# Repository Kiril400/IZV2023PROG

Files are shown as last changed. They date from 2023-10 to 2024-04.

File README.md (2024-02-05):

# Smart MeteoBox
Projekta galvenā ideja un mērķis ir izveidot digitālu ierīci, kas nodrošinās iespēju sēkot līdzi laikapstākļiem vidē, kur ierīce atrodas, mērot gaisa temperatūru, relatīvo gaisa mitrumu, kā arī atmosfēras spiedienu. Ierīce nodrošinās arī iespēju paredzēt laikapstākļus, balstoties uz augstāk minētiem lielumiem un šo lielumu izmaiņām laikā. Nepieciešamo informāciju ir paredzēts izvadīt uz ierīces ekrāna.
Projekta nosaukums ir Smart MeteoBox.

Izmantotās tehnoloģijas: C++, Arduino IDE. 

Dalībnieki: Kirils Koļesņikovs (darba plānā atzīmēts ar zaļo krāsu), Ilya Reutin (ar zilo), Varvara Gromova (ar oranžo)

Darba plāns 02/10 - 30/10:



Darba plāns 30/10 - 01/12:

Darba plāns 04/12 - 29/12:

Darba plāns 08/01 - 28/01

Darba plāns 05/02 - 02/03

Ierīces elektroshēma
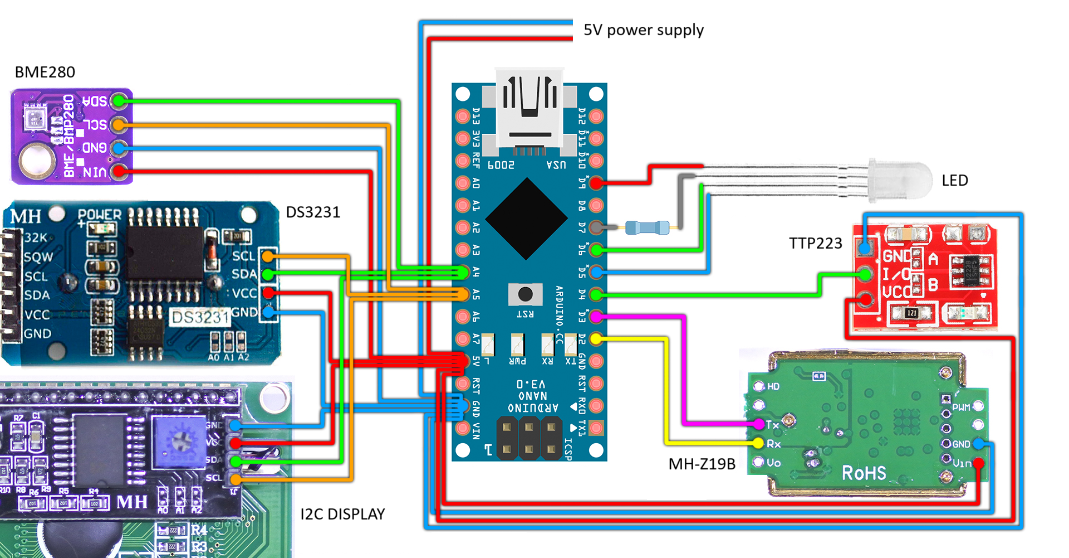
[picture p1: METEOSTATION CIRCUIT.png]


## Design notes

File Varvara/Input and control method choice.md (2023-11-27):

Sensoru pogām, kas pazīstamas arī kā kapacitatīvās skārienjutīgās vai skārienjutīgās pogas, ir priekšrocības salīdzinājumā ar tradicionālajām spiedpogu un potenciometriem, viens no galvenajiem ir izturība: sensoru pogām nav fizisku kustīgu detaļu, tādējādi samazinot to nolietojumu laika gaitā. Mehāniskās pogas var nolietoties atkārtotas lietošanas rezultātā, un potenciometri var nolietoties mehāniskā kontakta (berzes) dēļ.

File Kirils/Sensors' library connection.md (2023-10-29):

**Wire.h** - working. <BR> 
**GyverTime.h** - working, but some features are to be explored. <BR>
**GyverButton.h** - to do if we face trouble with button accident trigering. <BR>
**LiquidCrystal_I2C.h** - working. <BR>
**RTClib-master.h** - to do when sensor arrives. <BR>
**MHZ19_uart.h** - to do when sensor arrives. <BR>

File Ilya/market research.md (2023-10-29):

<h1>Portatīvo meteoroloģisko staciju un to funkcionalitātes tirgus izpēte</h1>
Portatīva meteostacijas ir kompaktas un multifunkcionālas ierīces, kas paredzētas, lai sniegtu aktuālo meteoroloģisko informāciju visdažādākajiem lietojumiem. Šajā tirgus pētījumā tiek izpētīti desmit dažādi portatīvo meteoroloģisko staciju modeļi, kā arī to galvenās funkcijas un īpašības, lai izspriestu, kādas funkcijas var padarīt jauno projektu par unikālu tirgū.<br>
<br>
<strong>1. Kestrel 5500 Weather Meter with LiNK:</strong><br>
Mājaslapa: https://kestrelmeters.com/products/kestrel-5500-weather-meter<br>
Funkcijas: mēra temperatūru, mitrumu, barometrisko spiedienu, vēja ātrumu, vēja virzienu, augstumu virs jūras līmeņa un aprēķina dažādus ar laikapstākļiem saistītus parametrus, piemēram, siltuma stresa indeksu un rasas punktu.<br>
<br>
<strong>2. Davis Instruments Vantage Vue Handheld Weather Station:</strong><br>
Mājaslapa: https://www.davisinstruments.com/products/vantage-vue-weather-station-with-weatherlink-console <br>
Funkcijas: Sniedz datus par temperatūru, mitrumu, barometrisko spiedienu, vēja ātrumu, vēja virzienu un nokrišņu daudzumu.<br>
<br>
<strong>3. AcuRite 01080M Pro Accuracy Portable Weather Station:</strong><br>
Mājaslapa: https://www.amazon.com/AcuRite-01080M-Accuracy-Temperature-Humidity/dp/B000XTJRRA <br>
Funkcijas: monitorē temperatūru, mitrumu, barometrisko spiedienu un vēja ātrumu. <br>
<br>
<strong>4. Ambient Weather WM-4 Handheld Weather Station:</strong><br>
Mājaslapa: https://ambientweather.com/amwm4-html <br>
Funkcijas: mēra temperatūru, vēja ātrumu, vēja virzienu un vēja vēsumu.<br>
<br>
<strong>5. Brunton ADC Pro Handheld Weather Station:</strong><br>
Mājaslapa: https://www.amazon.com/Brunton-Atmospherice-Data-Center-Wind/dp/B000FKMUDU?th=1 <br>
Funkcijas: sniedz datus par temperatūru, mitrumu, barometrisko spiedienu, augstumu un dažādām laikapstākļu prognozēm.<br>
<br>
<strong>6. La Crosse Technology C83332 Handheld Weather Station:</strong><br>
Mājaslapa: https://www.lacrossetechnology.com/products/c83332 <br>
Funkcijas: nosaka temperatūru, mitrumu, barometrisko spiedienu un augstumu virs jūras līmeņa.<br>
<br>
<strong>7. Proster Digital Anemometer Handheld Weather Station:</strong><br>
Mājaslapa: https://www.amazon.com/Proster-Anemometer-Thermometer-Backlight-Collection/dp/B01FTPX566 <br>
Funkcijas: Mēra vēja ātrumu, vēja vēsumu, temperatūru un mitrumu.<br>
<br>
<strong>8. Oregon Scientific BAR208HGX Handheld Weather Station:</strong><br>
Mājaslapa: https://www.oregonscientificstore.com/p-458-oregon-scientific-bar208hgx-advanced-wireless-weather-station-with-humidity-radio-controlled-clock-and-weather-forecast.a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 <br>
Funkcijas: sniedz datus par temperatūru, mitrumu, barometrisko spiedienu un laika prognozes.<br>
<br>
<strong>9. Casio Pro Trek PRG270-1 Handheld Weather Station Watch:</strong> <br>
Mājaslapa: https://www.casio.com/products/watches/pro-trek/prg270-1 <br>
Funkcijas: apvieno rokas pulksteni ar laikapstākļu funkcijām, tostarp temperatūru, barometrisko spiedienu, augstumu virs jūras līmeņa un kompasu.<br>
<br>
<strong>10. Skywatch Xplorer 1 Handheld Weather Station:</strong><br>
Mājaslapa: https://www.darrera.com/wp/en/product/12401-skywatch-xplorer-1/ <br>
Funkcijas: Mēra vēja ātrumu, temperatūru un vēja vēsumu. Tas ir kompakts un izturīgs.<br>
<br>
Lai gan šīs rokas meteoroloģiskās stacijas piedāvā virkni funkciju laikapstākļu izpētei, tām nav iespējas izvadīt laikapstākļu statistiku noteiktam laika periodam. Šī funkcija ir unikāls mūsu projekta aspekts, kas atšķir mūsu produktu no pārējiem tirgū esošajiem modeļiem.<br>

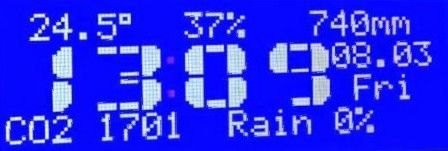
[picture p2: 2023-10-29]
Kirils/main screen design.jpg

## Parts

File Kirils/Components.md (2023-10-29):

**Arduino NANO:**<BR>
Kompakta plate, kas balstīta uz ATmega328P. Tā piedāvā tādu pašu funkcionalitāti kā Arduino Uno, bet mazākā iepakojumā.  

**Sensora poga (TTP223):**<BR> Ierīce, kas uztver fizisku ievadi pat caur planu plastiku un nosūta signālu mikrokontrolierim. Tā ir vienkārši lietojama un viegli intergrējama.

**BME280 (5V):**<BR> Precīzs Bosch sensors, kas mēra mitrumu, spiedienu un temperatūru. Liela precizitāte un zems enerģijas patēriņš.

**MH-Z19**:<BR> Infrasarkanais CO2 sensors iekštelpu gaisa kvalitātes monitorēšanai. To slavē par augstu jutību un ilgtermiņa stabilitāti.

**Display2004 i2c:**<BR> 20x4 rakstzīmju LCD modulis ar I2C interfeisu. To novērtē par tā lietošanas ērtumu un skaidru displeju.

**DS3231:** <BR>Ļoti precīzs reālā laika pulksteņa modulis. Tam ir integrēts temperatūras kompensēts kristāla oscilators, nodrošinot lielisku laika norādi.<br><br>
**Visas komponentes ir iegadajāmas Lemona.lv vai aliexpress.com**

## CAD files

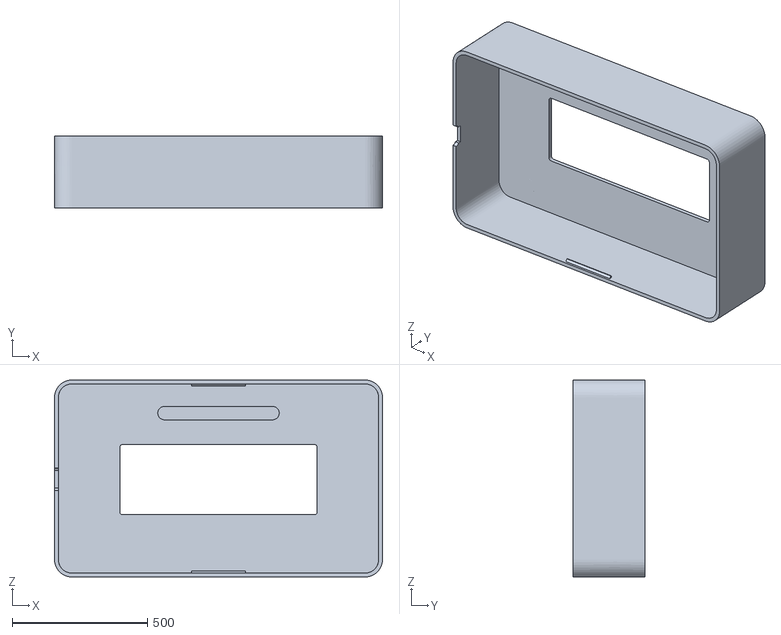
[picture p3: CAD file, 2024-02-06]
3D model/MeshBody1.stl
1213.8 x 265.0 x 728.8

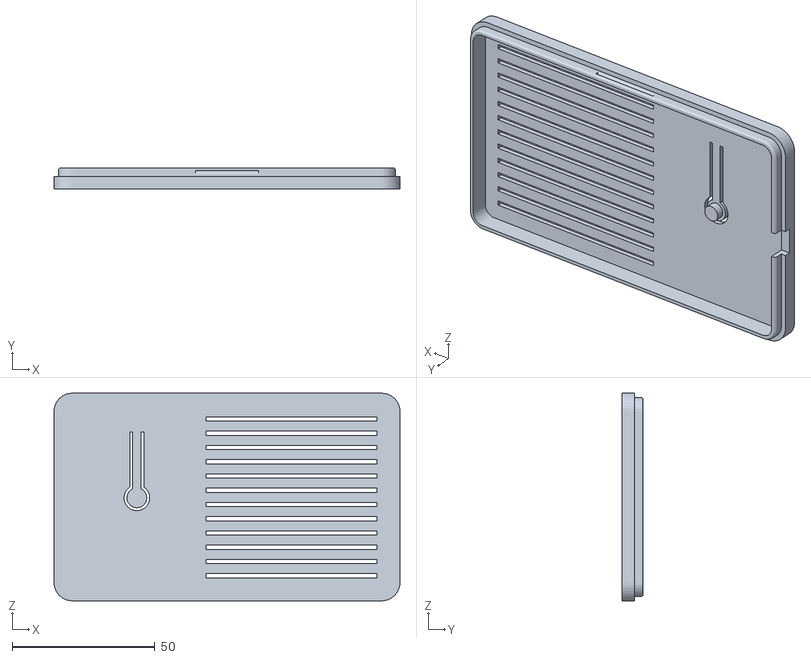
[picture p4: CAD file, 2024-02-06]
3D model/Meteo Clock Enclosure v16 - Back.stl
121.4 x 7.50 x 72.9

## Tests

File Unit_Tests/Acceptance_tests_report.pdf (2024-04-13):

## Smart MeteoBox: akcepttesti

Funkcijas, Darbības apraksts, nozīme | Ievade/Darbība | Sagaidāmais rezultāts | Rezultāts
Funkcija ciparu izvadīšanai uz ekrāna | DrawDIG(0) | Tiek izvadīts cipars 0 | Tiek izvadīts cipars 0
| drawDIG(1) | Tiek izvadīts cipars 1 | Tiek izvadīts cipars 1
| drawDIG(a) | Tiek izvadīta kļūda | Nekas netiek izvadīts
| drawDIG(+) | Tiek izvadīta kļūda | Nekas netiek izvadīts
Funkcija punktu un atstarpju izvadīšanai | drawdot(3,2,1) | Punkts ar koord. (3,1) | Punkts ar koord. (3,1)
| drawdot(8,1,1) | Punkts ar koord. (8,1) | Punkts ar koord. (8,1)
| drawdot(8,1,0) | Punkts netiek izvadīts | Punkts netiek izvadīts
| drawdot(40,1,1) | Tiek izvadīta kļūda | Nekas netiek izvadīts
| drawdot(a,1,1) | Tiek izvadīta kļūda | Nekas netiek izvadīts
Funkcija laika izvadīšanai uz ekrānā formātā hh,mm | drawClock(14,36) | Tiek izvadīts laiks 14,36 | Tiek izvadīts laiks 14,36
| drawClock(23,59) | Tiek izvadīts laiks 23,59 | Tiek izvadīts laiks 23,59
| drawClock(0,00) | Tiek izvadīts laiks 0,00 | Tiek izvadīts laiks 0,00
| drawClock(1,89) | Tiek izvadīta kļūda | Tiek izvadīts laika 1,89
| drawClock(a,19) | Tiek izvadīta kļūda | Nekas netiek izvadīts
Funkcija datuma izvadīšanai uz ekrānā formātā dd,mm | drawData(15,07) | Tiek izvadīts datums 15,07 | Tiek izvadīts datums 15,07
| drawData(2,3) | Tiek izvadīts datums 2,3 | Tiek izvadīts datums 2,3
| drawData(1,1) | Tiek izvadīts datums 1,1 | Tiek izvadīts datums 1,1
| drawData(31,12) | Tiek izvadīts datums 31,12 | Tiek izvadīts datums 31,12
| drawData(30,2) | Tiek izvadīta kļūda | Tiek izvadīts datums 30,2
| drawData(a,2) | Tiek izvadīta kļūda | Nekas netiek izvadīts
Funkcija LED gaismas krāsu definēšanai | setLED(0) | Nespīd | Nespīd
| setLED(1) | Spīd sarkana gaisma | Spīd sarkanā gaisma
| setLED(2) | Spīd zaļā gaisma | Spīd zaļā gaisma
| setLED(3) | Spīd zilā gaisma | Spīd zilā gaisma
| setLED(4) | Nekas nenotiek | Nekas nenotiek
| setLED(a) | Nekas nenotiek | Nekas nenotiek
Funkcija ekrāna spilgtuma mainīšanai atkarībā no apkārtējas vides | checkBrightness(analogRead(LIGHT_SENS) < BRIGHT_LIMIT) | Ekrāns kļūst tumšāks | Ekrāns kļūst tumšāks
| checkBrightness(analogRead(LIGHT_SENS) > BRIGHT_LIMIT) | Ekrāns kļūst gaišāks | Ekrāns kļūst gaišāks

Funkcija ekrānu pārslēgšanai ar pogu | modesTick(button.isClick()) | Ekrāns pārslēdzas uz nākamo | Ekrāns nepārslēdzas uz nākamo
| modesTick(button.isHolded()) | Ekrāns pārslēdzas uz galveno | Ekrāns nepārslēdzas uz galveno
| redrawPlot(1) | Zīmē temperatūras grafiku pēdejās stundas laikā | Zīmē temperatūras grafiku pēdejās stundas laikā
| redrawPlot(2) | Zīmē temperatūras grafiku pēdējo 24 stundu laikā | Zīmē temperatūras grafiku pēdējo 24 stundu laikā
| redrawPlot(3) | Zīmē relatīvā mitruma grafiku pēdejās stundas laikā | Zīmē relatīvā mitruma grafiku pēdejās stundas laikā
| redrawPlot(4) | Zīmē relatīvā mitruma grafiku pēdējo 24 stundu laikā | Zīmē relatīvā mitruma grafiku pēdējo 24 stundu laikā
| redrawPlot(5) | Zīmē spiediena grafiku pēdejās stundas laikā | Zīmē spiediena grafiku pēdejās stundas laikā
| redrawPlot(6) | Zīmē spiediena grafiku pēdējo 24 stundu laikā | Zīmē spiediena grafiku pēdējo 24 stundu laikā
| redrawPlot(7) | Zīmē CO2 līmeņa grafiku pēdejās stundas laikā | Zīmē CO2 līmeņa grafiku pēdejās stundas laikā
| redrawPlot(8) | Zīmē CO2 līmeņa grafiku pēdējo 24 stundu laikā | Zīmē CO2 līmeņa grafiku pēdējo 24 stundu laikā
| redrawPlot(9) | Izvada kļūdu | Nekas netiek izvadīts
| redrawPlot(a) | Izvada kļūdu | Nekas netiek izvadīts
Funkcija datu pieprasīšanai no sensoriem un CO2 līmeņa attēlošanai | readSensors(19, 51, 101325, 650) | Temperatūrai jābūt intervālā -40 - 40; Relatīvajam mitrumam jabūt 0 -100% Spiediena vērtībai jābūt ap 100000Pa (jeb 750mmHg) CO2 limenis mazāks par 800ppm – iedegas zaļā gaisma | Temperatūra: 19 Relatīvais mitrums: 51 Spiediens: 760mmHg CO2 limenis: 650ppm – iedegas zaļā gaisma
| readSensors(19, 51, 101325, 910) | CO2 līmenis ir 800-1200ppm intervālā, deg zilā gaisma | Iedegas zilā gaisma
| readSensors(19, 51, 101325, 1350) | CO2 līmenis ir virs 1200ppm intervālā, deg sarkanā gaisma | Iedegas sarkanā gaisma
Funkcija sensoru nolasītu datu izvadīšanai formātā: T° Hum% CO2 ppm p mm rain __% | drawSensors(23, 34, 674, 760, 20) | Attēlo datus formātā 23° 34% 674 ppm 760 mm rain 20% | Attēlo datus formātā 23° 34% 674 ppm 760 mm rain 20%

Funkcija grafiku
izvadīšanai uz
ekrāna

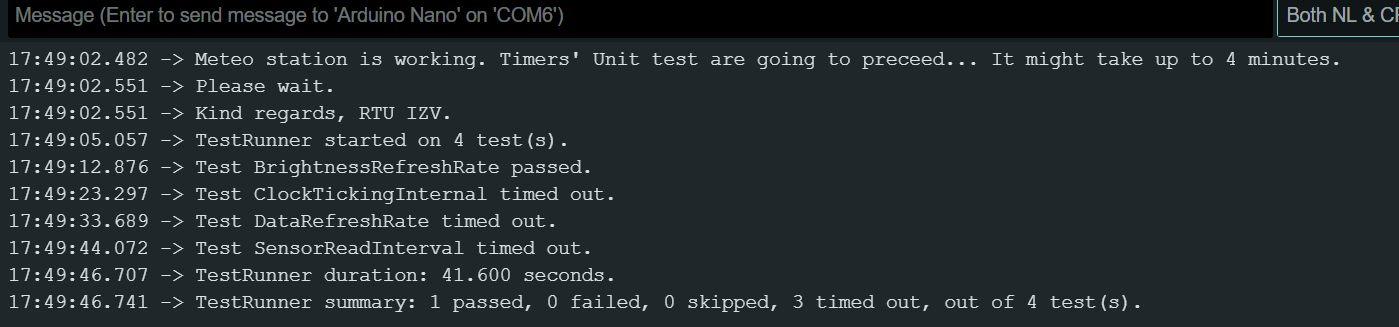
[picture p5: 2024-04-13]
Unit_Tests/Tests are not passed example.png

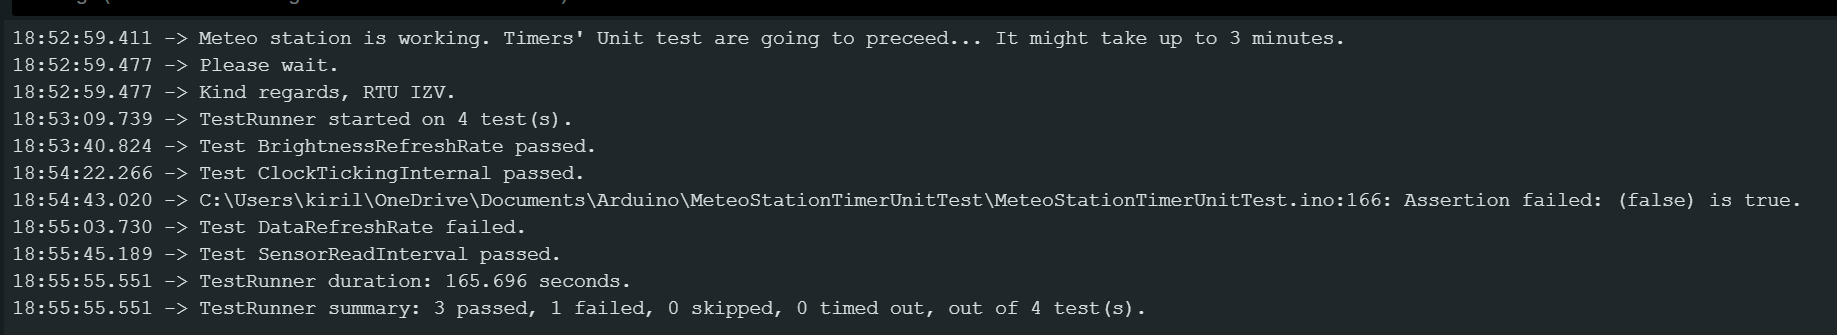
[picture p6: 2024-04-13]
Unit_Tests/Tests are not passed example 1.png

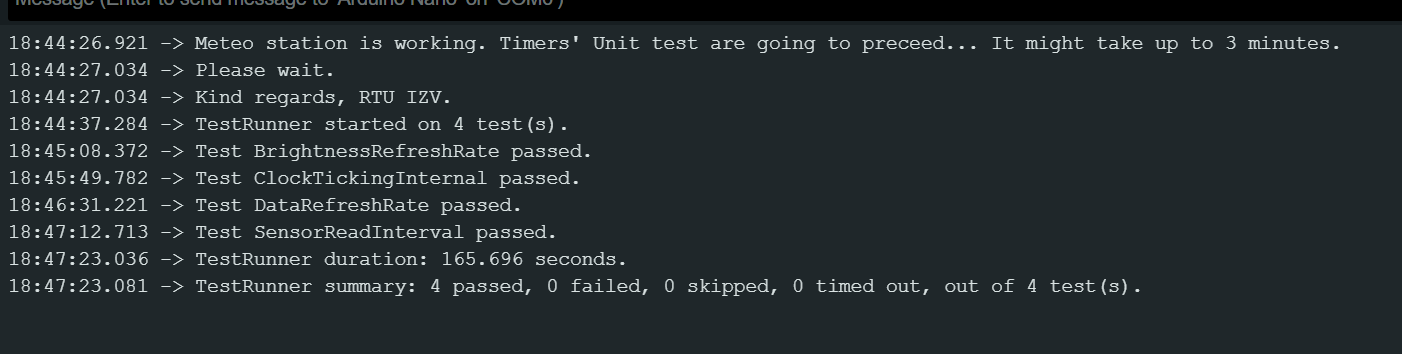
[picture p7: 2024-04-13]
Unit_Tests/Tests are passed example.png

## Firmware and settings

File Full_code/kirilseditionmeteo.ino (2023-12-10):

// ------------------------- SETTINGS --------------------
#define RST_CLK 0       // Reset clock to firmware loading time
#define SENSOR_TIME 30000     // Sensor reading update time on the screen, milliseconds
#define LED_TYPE 0          // RGB LED type: 0 - common cathode, 1 - common anode

// Brightness control
#define BRIGHT_LIMIT 150  // Signal level below which brightness will switch to minimum (0-1023)
#define LED_MAX_BR 255    // Maximum CO2 LED brightness (0 - 255)
#define LED_MIN_BR 10     // Minimum CO2 LED brightness (0 - 255)
#define LCD_MAX_BR 255    // Maximum LCD backlight brightness (0 - 255)
#define LCD_MIN_BR 10     // Minimum LCD backlight brightness (0 - 255)
#define DISPLAY_I2C_ADDR 0x27   // Display board I2C address
// Display limits for graphs
#define MIN_TEMP 15
#define MAX_TEMP 35
#define MIN_HUM 0
#define MAX_HUM 100
#define MIN_PRESS -100
#define MAX_PRESS 100
#define MIN_CO2 300
#define MAX_CO2 2000

// Pins
#define DISP_LIGHT 10
#define LIGHT_SENS A3

#define RX_MHZ 2
#define TX_MHZ 3

#define LED_COMMON_PIN 7
#define LED_RED_PIN 9
#define LED_GREEN_PIN 6
#define LED_BLUE_PIN 5
#define SENSOR_BUTTON_PIN 4

#define DISP_BACKLIT_PIN 10     // Display backlight pin
#define LIGHT_SENS_PIN 0   // Photoresistor pin

// Libraries
#include <Wire.h>
#include <LiquidCrystal_I2C.h>

LiquidCrystal_I2C LCD_DISP(DISPLAY_I2C_ADDR, 20, 4);

#include "RTClib.h"
RTC_DS3231 rtc;
DateTime RealTime;

#include <Adafruit_Sensor.h>
#include <Adafruit_BME280.h>
#define SEALEVELPRESSURE_HPA (1013.25)
Adafruit_BME280 BME_SENS;

#include <MHZ19_uart.h>
MHZ19_uart MHZ_SENS;

#include <GyverTimer.h>
GTimer_ms sensorsTimer(SENSOR_TIME);
GTimer_ms drawSensorsTimer(SENSOR_TIME);
GTimer_ms clockTimer(500);
GTimer_ms hourPlotTimer((long)4 * 60 * 1000);         // 4 minutes
GTimer_ms dayPlotTimer((long)1.6 * 60 * 60 * 1000);   // 1.6 hours
GTimer_ms plotTimer(240000);
GTimer_ms predictTimer((long)10 * 60 * 1000);         // 10 minutes
GTimer_ms brightTimer(2000);

#include "GyverButton.h"
GButton button(SENSOR_BUTTON_PIN, LOW_PULL, NORM_OPEN);

int8_t hrs, mins, secs;
byte mode = 0;
/*
  0 clock and data
  1 temperature graph for the hour
  2 temperature graph for the day
  3 humidity graph for the hour
  4 humidity graph for the day
  5 pressure graph for the hour
  6 pressure graph for the day
  7 CO2 graph for the hour
  8 CO2 graph for the day
*/

// Variables for display
float dispTemp;
byte dispHum;
int dispPres;
int dispCO2;
int dispRain;

// Arrays for graphs
int tempHour[15], tempDay[15];
int humHour[15], humDay[15];
int pressHour[15], pressDay[15];
int co2Hour[15], co2Day[15];
int delta;
uint32_t pressure_array[6];
uint32_t sumX, sumY, sumX2, sumXY;
float a, b;
byte time_array[6];

// Characters
// Graph

byte row8[8] = {0b11111,  0b11111,  0b11111,  0b11111,  0b11111,  0b11111,  0b11111,  0b11111};
byte row7[8] = {0b00000,  0b11111,  0b11111,  0b11111,  0b11111,  0b11111,  0b11111,  0b11111};
byte row6[8] = {0b00000,  0b00000,  0b11111,  0b11111,  0b11111,  0b11111,  0b11111,  0b11111};
byte row5[8] = {0b00000,  0b00000,  0b00000,  0b11111,  0b11111,  0b11111,  0b11111,  0b11111};
byte row4[8] = {0b00000,  0b00000,  0b00000,  0b00000,  0b11111,  0b11111,  0b11111,  0b11111};
byte row3[8] = {0b00000,  0b00000,  0b00000,  0b00000,  0b00000,  0b11111,  0b11111,  0b11111};
byte row2[8] = {0b00000,  0b00000,  0b00000,  0b00000,  0b00000,  0b00000,  0b11111,  0b11111};
byte row1[8] = {0b00000,  0b00000,  0b00000,  0b00000,  0b00000,  0b00000,  0b00000,  0b11111};

// numbers
uint8_t LT[8] = {0b00111,  0b01111,  0b11111,  0b11111,  0b11111,  0b11111,  0b11111,  0b11111};
uint8_t UB[8] = {0b11111,  0b11111,  0b11111,  0b00000,  0b00000,  0b00000,  0b00000,  0b00000};
uint8_t RT[8] = {0b11100,  0b11110,  0b11111,  0b11111,  0b11111,  0b11111,  0b11111,  0b11111};
uint8_t LL[8] = {0b11111,  0b11111,  0b11111,  0b11111,  0b11111,  0b11111,  0b01111,  0b00111};
uint8_t LB[8] = {0b00000,  0b00000,  0b00000,  0b00000,  0b00000,  0b11111,  0b11111,  0b11111};
uint8_t LR[8] = {0b11111,  0b11111,  0b11111,  0b11111,  0b11111,  0b11111,  0b11110,  0b11100};
uint8_t UMB[8] = {0b11111,  0b11111,  0b11111,  0b00000,  0b00000,  0b00000,  0b11111,  0b11111};
uint8_t LMB[8] = {0b11111,  0b00000,  0b00000,  0b00000,  0b00000,  0b11111,  0b11111,  0b11111};

void drawDig(byte dig, byte x, byte y) {
  switch (dig) {
    case 0:
      LCD_DISP.setCursor(x, y); // set cursor to column 0, line 0 (first row)
      LCD_DISP.write(0);  // call each segment to create
      LCD_DISP.write(1);  // top half of the number
      LCD_DISP.write(2);
      LCD_DISP.setCursor(x, y + 1); // set cursor to colum 0, line 1 (second row)
      LCD_DISP.write(3);  // call each segment to create
      LCD_DISP.write(4);  // bottom half of the number
      LCD_DISP.write(5);
      break;
    case 1:
      LCD_DISP.setCursor(x + 1, y);
      LCD_DISP.write(1);
      LCD_DISP.write(2);
      LCD_DISP.setCursor(x + 2, y + 1);
      LCD_DISP.write(5);
      break;
    case 2:
      LCD_DISP.setCursor(x, y);
      LCD_DISP.write(6);
      LCD_DISP.write(6);
      LCD_DISP.write(2);
      LCD_DISP.setCursor(x, y + 1);
      LCD_DISP.write(3);
      LCD_DISP.write(7);
      LCD_DISP.write(7);
      break;
    case 3:
      LCD_DISP.setCursor(x, y);
      LCD_DISP.write(6);
      LCD_DISP.write(6);
      LCD_DISP.write(2);
      LCD_DISP.setCursor(x, y + 1);
      LCD_DISP.write(7);
      LCD_DISP.write(7);
      LCD_DISP.write(5);
      break;
    case 4:
      LCD_DISP.setCursor(x, y);
      LCD_DISP.write(3);
      LCD_DISP.write(4);
      LCD_DISP.write(2);
      LCD_DISP.setCursor(x + 2, y + 1);
      LCD_DISP.write(5);
      break;
    case 5:
      LCD_DISP.setCursor(x, y);
      LCD_DISP.write(0);
      LCD_DISP.write(6);
      LCD_DISP.write(6);
      LCD_DISP.setCursor(x, y + 1);
      LCD_DISP.write(7);
      LCD_DISP.write(7);
      LCD_DISP.write(5);
      break;
    case 6:
      LCD_DISP.setCursor(x, y);
      LCD_DISP.write(0);
      LCD_DISP.write(6);
      LCD_DISP.write(6);
      LCD_DISP.setCursor(x, y + 1);
      LCD_DISP.write(3);
      LCD_DISP.write(7);
      LCD_DISP.write(5);
      break;
    case 7:
      LCD_DISP.setCursor(x, y);
      LCD_DISP.write(1);
      LCD_DISP.write(1);
      LCD_DISP.write(2);
      LCD_DISP.setCursor(x + 1, y + 1);
      LCD_DISP.write(0);
      break;
    case 8:
      LCD_DISP.setCursor(x, y);
      LCD_DISP.write(0);
      LCD_DISP.write(6);
      LCD_DISP.write(2);
      LCD_DISP.setCursor(x, y + 1);
      LCD_DISP.write(3);
      LCD_DISP.write(7);
      LCD_DISP.write(5);
      break;
    case 9:
      LCD_DISP.setCursor(x, y);
      LCD_DISP.write(0);
      LCD_DISP.write(6);
      LCD_DISP.write(2);
      LCD_DISP.setCursor(x + 1, y + 1);
      LCD_DISP.write(4);
      LCD_DISP.write(5);
      break;
    case 10:
      LCD_DISP.setCursor(x, y);
      LCD_DISP.write(32);
      LCD_DISP.write(32);
      LCD_DISP.write(32);
      LCD_DISP.setCursor(x, y + 1);
      LCD_DISP.write(32);
      LCD_DISP.write(32);
      LCD_DISP.write(32);
      break;
  }
}

void drawdots(byte x, byte y, boolean state) {
  byte code;
  if (state) code = 165;
  else code = 32;
  LCD_DISP.setCursor(x, y);
  LCD_DISP.write(code);
  LCD_DISP.setCursor(x, y + 1);
  LCD_DISP.write(code);
}

void drawClock(byte hours, byte minutes, byte x, byte y, boolean dotState) {
  // make it blank 
  LCD_DISP.setCursor(x, y);
  LCD_DISP.print("               ");
  LCD_DISP.setCursor(x, y + 1);
  LCD_DISP.print("               ");

  //if (hours > 23 || minutes > 59) return;
  if (hours / 10 == 0) drawDig(10, x, y);
  else drawDig(hours / 10, x, y);
  drawDig(hours % 10, x + 4, y);
  drawDig(minutes / 10, x + 8, y);
  drawDig(minutes % 10, x + 12, y);
}


static const char *dayNames[]  = {
  "Sund",
  "Mond",
  "Tues",
  "Wedn",
  "Thur",
  "Frid",
  "Satu",
};


void drawData() {
  LCD_DISP.setCursor(15, 0);
  if (RealTime.day() < 10) LCD_DISP.print(0);
  LCD_DISP.print(RealTime.day());
  LCD_DISP.print(".");
  if (RealTime.month() < 10) LCD_DISP.print(0);
  LCD_DISP.print(RealTime.month());

}

void drawPlot(byte pos, byte row, byte width, byte height, int min_val, int max_val, int *plot_array, String label) {
  int max_value = -32000;
  int min_value = 32000;

  for (byte i = 0; i < 15; i++) {
    if (plot_array[i] > max_value) max_value = plot_array[i];
    if (plot_array[i] < min_value) min_value = plot_array[i];
  }
  LCD_DISP.setCursor(16, 0); LCD_DISP.print(max_value);
  LCD_DISP.setCursor(16, 1); LCD_DISP.print(label);
  LCD_DISP.setCursor(16, 2); LCD_DISP.print(plot_array[14]);
  LCD_DISP.setCursor(16, 3); LCD_DISP.print(min_value);

  for (byte i = 0; i < width; i++) {                  // For each column of parameters
    int fill_val = plot_array[i];
    fill_val = constrain(fill_val, min_val, max_val);
    byte infill, fract;
    // Find the number of full blocks considering the minimum and maximum for graph display
    if (plot_array[i] > min_val)
      infill = floor((float)(plot_array[i] - min_val) / (max_val - min_val) * height * 10);
    else infill = 0;
    fract = (float)(infill % 10) * 8 / 10;                   // Find the number of remaining stripes
    infill = infill / 10;

    for (byte n = 0; n < height; n++) {     // For each line of the graph
      if (n < infill && infill > 0) {       // While we are below the level
        LCD_DISP.setCursor(i, (row - n));        // Fill with full cells
        LCD_DISP.write(0);
      }
      if (n >= infill) {                    // If we reached the level
        LCD_DISP.setCursor(i, (row - n));
        if (fract > 0) LCD_DISP.write(fract);          // Fill with fractional cells
        else LCD_DISP.write(16);                       // If fractional is 0, fill with empty
        for (byte k = n + 1; k < height; k++) {   // Fill everything above with empty
          LCD_DISP.setCursor(i, (row - k));
          LCD_DISP.write(16);
        }
        break;
      }
    }
  }
}


void loadClock() {
  LCD_DISP.createChar(0, LT);
  LCD_DISP.createChar(1, UB);
  LCD_DISP.createChar(2, RT);
  LCD_DISP.createChar(3, LL);
  LCD_DISP.createChar(4, LB);
  LCD_DISP.createChar(5, LR);
  LCD_DISP.createChar(6, UMB);
  LCD_DISP.createChar(7, LMB);
}

void loadPlot() {
  LCD_DISP.createChar(0, row8);
  LCD_DISP.createChar(1, row1);
  LCD_DISP.createChar(2, row2);
  LCD_DISP.createChar(3, row3);
  LCD_DISP.createChar(4, row4);
  LCD_DISP.createChar(5, row5);
  LCD_DISP.createChar(6, row6);
  LCD_DISP.createChar(7, row7);
}

#if (LED_TYPE == 0)
byte LED_ON = (LED_MAX_BR);
byte LED_OFF = (LED_MIN_BR);
#else
byte LED_ON = (255 - LED_MAX_BR);
byte LED_OFF = (255 - LED_MIN_BR);
#endif

void setLED(byte color) {
  // at first turn everything off 
  if (!LED_TYPE) {
    analogWrite(LED_RED_PIN, 0);
    analogWrite(LED_GREEN_PIN, 0);
    analogWrite(LED_BLUE_PIN, 0);
  } else {
    analogWrite(LED_RED_PIN, 255);
    analogWrite(LED_GREEN_PIN, 255);
    analogWrite(LED_BLUE_PIN, 255);
  }
  switch (color) {    // 0 off, 1 red, 2 green, 3 blue 
    case 0:
      break;
    case 1: analogWrite(LED_RED_PIN, LED_ON);
      break;
    case 2: analogWrite(LED_GREEN_PIN, LED_ON);
      break;
    case 3: analogWrite(LED_BLUE_PIN, LED_ON);
      break;
  }
}

void setup() {
  Serial.begin(9600);

  pinMode(DISP_LIGHT, OUTPUT);
  pinMode(LED_COMMON_PIN, OUTPUT);
  pinMode(LED_RED_PIN, OUTPUT);
  pinMode(LED_GREEN_PIN, OUTPUT);
  pinMode(LED_BLUE_PIN, OUTPUT);
  setLED(0);

  digitalWrite(LED_COMMON_PIN, LED_TYPE);
  analogWrite(DISP_LIGHT, LCD_MAX_BR);

  LCD_DISP.init();
  LCD_DISP.backlight();
  LCD_DISP.clear();

#if (true)
  boolean status = true;

  setLED(1);


  LCD_DISP.setCursor(0, 0);
  LCD_DISP.print(F("MHZ-19... "));
  Serial.print(F("MHZ-19... "));
  MHZ_SENS.begin(TX_MHZ, RX_MHZ);
  MHZ_SENS.setAutoCalibration(false);
  MHZ_SENS.getStatus();    // asking for the first time, response always - 1
  delay(500);
  if (MHZ_SENS.getStatus() == 0) {
    LCD_DISP.print(F("OK"));
    Serial.println(F("OK"));
  } else {
    LCD_DISP.print(F("ERROR"));
    Serial.println(F("ERROR"));
    status = false;
  }


  setLED(2);
  LCD_DISP.setCursor(0, 1);
  LCD_DISP.print(F("RTC... "));
  Serial.print(F("RTC... "));
  delay(50);
  if (rtc.begin()) {
    LCD_DISP.print(F("OK"));
    Serial.println(F("OK"));
  } else {
    LCD_DISP.print(F("ERROR"));
    Serial.println(F("ERROR"));
    status = false;
  }

  setLED(3);
  LCD_DISP.setCursor(0, 2);
  LCD_DISP.print(F("BME280... "));
  Serial.print(F("BME280... "));
  delay(50);
  if (BME_SENS.begin(&Wire)) {
    LCD_DISP.print(F("OK"));
    Serial.println(F("OK"));
  } else {
    LCD_DISP.print(F("ERROR"));
    Serial.println(F("ERROR"));
    status = false;
  }

  setLED(0);
  LCD_DISP.setCursor(0, 3);
  if (status) {
    LCD_DISP.print(F("All good"));
    Serial.println(F("All good"));
  } else {
    LCD_DISP.print(F("Check wires!"));
    Serial.println(F("Check wires!"));
  }
  while (1) {
    LCD_DISP.setCursor(14, 1);
    LCD_DISP.print("P:    ");
    LCD_DISP.setCursor(16, 1);
    LCD_DISP.print(analogRead(LIGHT_SENS), 1);
    Serial.println(analogRead(LIGHT_SENS));
    delay(300);
  }
#else


  MHZ_SENS.begin(TX_MHZ, RX_MHZ);
  MHZ_SENS.setAutoCalibration(false);

  rtc.begin();
  BME_SENS.begin(&Wire);
#endif

  BME_SENS.setSampling(Adafruit_BME280::MODE_FORCED,
                  Adafruit_BME280::SAMPLING_X1, // temperature
                  Adafruit_BME280::SAMPLING_X1, // pressure
                  Adafruit_BME280::SAMPLING_X1, // humidity
                  Adafruit_BME280::FILTER_OFF   );

  if (RST_CLK || rtc.lostPower())
    rtc.adjust(DateTime(F(__DATE__), F(__TIME__)));

  RealTime = rtc.now();
  secs = RealTime.second();
  mins = RealTime.minute();
  hrs = RealTime.hour();

  BME_SENS.takeForcedMeasurement();
  uint32_t Pressure = BME_SENS.readPressure();
  for (byte i = 0; i < 6; i++) {   // counter from 0 to 5
    pressure_array[i] = Pressure;  // fill with current pressure 
    time_array[i] = i;             // fill with numbers 0 - 5
  }

  if (true
) {
    loadClock();
    drawClock(hrs, mins, 0, 0, 1);
    drawData();
  }
  readSensors();
  drawSensors();
}

void loop() {
  if (brightTimer.isReady()) checkBrightness(); // Check brightness
  if (sensorsTimer.isReady()) readSensors();    // Read sensor readings periodically

#if (true)
  if (clockTimer.isReady()) clockTick();        // Recalculate time twice a second and blink dots
  plotSensorsTick();                            // Here are several timers for recalculating graphs (hourly, daily, and forecast)
  modesTick();                                  // Here we catch button presses and switch modes
  if (mode == 0) {                                  // In the "main screen" mode
    if (drawSensorsTimer.isReady()) drawSensors();  // Update sensor readings on the display periodically
  } else {                                          // In any of the graph modes
    if (plotTimer.isReady()) redrawPlot();          // Redraw the graph
  }
#else
  if (drawSensorsTimer.isReady()) drawSensors();
#endif
}

void checkBrightness() {
  if (analogRead(LIGHT_SENS) < BRIGHT_LIMIT) {   // if dark
    analogWrite(DISP_LIGHT, LCD_MIN_BR);
#if (LED_TYPE == 0)
    LED_ON = (LED_MIN_BR);
#else
    LED_ON = (255 - LED_MIN_BR);
#endif
  } else {                                      // if not dark
    analogWrite(DISP_LIGHT, LCD_MAX_BR);
#if (LED_TYPE == 0)
    LED_ON = (LED_MAX_BR);
#else
    LED_ON = (255 - LED_MAX_BR);
#endif
  }
  if (dispCO2 < 800) setLED(2);
  else if (dispCO2 < 1200) setLED(3);
  else if (dispCO2 >= 1200) setLED(1);
}

void modesTick() {
  button.tick();
  boolean changeFlag = false;
  if (button.isClick()) {
    mode++;

#if (true)
    if (mode > 8) mode = 0;
#else
    if (mode > 6) mode = 0;
#endif
    changeFlag = true;
  }
  if (button.isHolded()) {
    mode = 0;
    changeFlag = true;
  }

  if (changeFlag) {
    if (mode == 0) {
      LCD_DISP.clear();
      loadClock();
      drawClock(hrs, mins, 0, 0, 1);
      drawData();
      drawSensors();
    } else {
      LCD_DISP.clear();
      loadPlot();
      redrawPlot();
    }
  }
}

void redrawPlot() {
  LCD_DISP.clear();
  switch (mode) {
    case 1: drawPlot(0, 3, 15, 4, MIN_TEMP, MAX_TEMP, (int*)tempHour, "t hr");
      break;
    case 2: drawPlot(0, 3, 15, 4, MIN_TEMP, MAX_TEMP, (int*)tempDay, "t day");
      break;
    case 3: drawPlot(0, 3, 15, 4, MIN_HUM, MAX_HUM, (int*)humHour, "h hr");
      break;
    case 4: drawPlot(0, 3, 15, 4, MIN_HUM, MAX_HUM, (int*)humDay, "h day");
      break;
    case 5: drawPlot(0, 3, 15, 4, MIN_PRESS, MAX_PRESS, (int*)pressHour, "p hr");
      break;
    case 6: drawPlot(0, 3, 15, 4, MIN_PRESS, MAX_PRESS, (int*)pressDay, "p day");
      break;
    case 7: drawPlot(0, 3, 15, 4, MIN_CO2, MAX_CO2, (int*)co2Hour, "c hr");
      break;
    case 8: drawPlot(0, 3, 15, 4, MIN_CO2, MAX_CO2, (int*)co2Day, "c day");
      break;
  }
}

void readSensors() {
  BME_SENS.takeForcedMeasurement();
  dispTemp = BME_SENS.readTemperature();
  dispHum = BME_SENS.readHumidity();
  dispPres = (float)BME_SENS.readPressure() * 0.00750062;
  dispCO2 = MHZ_SENS.getPPM();

  if (dispCO2 < 800) setLED(2);
  else if (dispCO2 < 1200) setLED(3);
  else if (dispCO2 >= 1200) setLED(1);

}

void drawSensors() {
  LCD_DISP.setCursor(0, 2);
  LCD_DISP.print(String(dispTemp, 1));
  LCD_DISP.write(223);
  LCD_DISP.setCursor(6, 2);
  LCD_DISP.print(" " + String(dispHum) + "%  ");

  LCD_DISP.print(String(dispCO2) + " ppm");
  if (dispCO2 < 1000) LCD_DISP.print(" ");

  LCD_DISP.setCursor(0, 3);
  LCD_DISP.print(String(dispPres) + " mm  rain ");
  LCD_DISP.print(F("       "));
  LCD_DISP.setCursor(13, 3);
  LCD_DISP.print(String(dispRain) + "%");  
}

void plotSensorsTick() {
  // 4 min timer
  if (hourPlotTimer.isReady()) {
    for (byte i = 0; i < 14; i++) {
      tempHour[i] = tempHour[i + 1];
      humHour[i] = humHour[i + 1];
      pressHour[i] = pressHour[i + 1];
      co2Hour[i] = co2Hour[i + 1];
    }
    tempHour[14] = dispTemp;
    humHour[14] = dispHum;
    co2Hour[14] = dispCO2;

    pressHour[14] = dispRain;
    
  }

  // 1.5 hour timer 
  if (dayPlotTimer.isReady()) {
    long averTemp = 0, averHum = 0, averPress = 0, averCO2 = 0;

    for (byte i = 0; i < 15; i++) {
      averTemp += tempHour[i];
      averHum += humHour[i];
      averPress += pressHour[i];
      averCO2 += co2Hour[i];
    }
    averTemp /= 15;
    averHum /= 15;
    averPress /= 15;
    averCO2 /= 15;

    for (byte i = 0; i < 14; i++) {
      tempDay[i] = tempDay[i + 1];
      humDay[i] = humDay[i + 1];
      pressDay[i] = pressDay[i + 1];
      co2Day[i] = co2Day[i + 1];
    }
    tempDay[14] = averTemp;
    humDay[14] = averHum;
    pressDay[14] = averPress;
    co2Day[14] = averCO2;
  }

  // 10 min timer 
 if (predictTimer.isReady()) {
    // Here we perform linear approximation for weather prediction
    long averPress = 0;
    for (byte i = 0; i < 10; i++) {
      BME_SENS.takeForcedMeasurement();
      averPress += BME_SENS.readPressure();
      delay(1);
    }
    averPress /= 10;

    for (byte i = 0; i < 5; i++) {                   // Counter from 0 to 5 (yes, up to 5, because 4 is less than 5)
      pressure_array[i] = pressure_array[i + 1];     // Shift the pressure array back one step, except for the last element
    }
    pressure_array[5] = averPress;                    // The last element of the array is now the new pressure
    sumX = 0;
    sumY = 0;
    sumX2 = 0;
    sumXY = 0;
    for (int i = 0; i < 6; i++) {                    // For all elements of the array
      sumX += time_array[i];
      sumY += (long)pressure_array[i];
      sumX2 += time_array[i] * time_array[i];
      sumXY += (long)time_array[i] * pressure_array[i];
    }
    a = 0;
    a = (long)6 * sumXY;             // Calculate the slope coefficient of the line
    a = a - (long)sumX * sumY;
    a = (float)a / (6 * sumX2 - sumX * sumX);
    delta = a * 6;      // Calculate the change in pressure
    dispRain = map(delta, -250, 250, 100, -100);  // Convert to percentage
  }
}

boolean dotFlag;
void clockTick() {
  dotFlag = !dotFlag;
  if (dotFlag) {          // Recalculate time every second
    secs++;
    if (secs > 59) {      // Every minute
      secs = 0;
      mins++;
      if (mins <= 59 && mode == 0) drawClock(hrs, mins, 0, 0, 1);
    }
    if (mins > 59) {      // Every hour
      RealTime = rtc.now();
      secs = RealTime.second();
      mins = RealTime.minute();
      hrs = RealTime.hour();
      if (mode == 0) drawClock(hrs, mins, 0, 0, 1);
      if (hrs > 23) {
        hrs = 0;
      }
      if (mode == 0 ) drawData();
    }

    
      LCD_DISP.setCursor(16, 1);
      if (secs < 10) LCD_DISP.print(" ");
      LCD_DISP.print(secs);
    
  }
  if (mode == 0) drawdots(7, 0, dotFlag);
  if (dispCO2 >= 1200) {
    if (dotFlag) setLED(1);
    else setLED(0);
  }
}

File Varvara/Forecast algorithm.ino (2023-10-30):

#include <Wire.h>
#include <Adafruit_Sensor.h>
#include <Adafruit_BMP280.h>

#include "RTClib.h"

#define SEALEVELPRESSURE_HPA (1013.25)

RTC_DS3231 rtc;   // initialise the RTC DS3231
Adafruit_BMP280 BMP;  // initialise the BMP280 sensor (example sensor)

unsigned long delayTime;  // refresh rate for the readings
int t_hour = 0;
int t_minute = 0;
//int t_second =0;

int pressureArray[10] = {0};  // here we store the pressure readings 
byte counter = 0;
byte delta_time = 0;
int Z = 0;

char tStr[21];
char pStr[22];
char hStr[20];
char pseaStr[26];
char timeStr[6];
char dateStr[12];
char zambretti[10] = "N/A";
char pressureHistory[57];
char pressureHistory2[57];

int temperature;
int humidity;
int pressure;
int altitude = 724;   // sheit reals altitude(googlable - for riga would be 7);


void setup() {
  bool status;
  Serial.begin(4800);   // default settings
  
  Serial.print(" Zambretti Weather      forecaster      ");
  delay(5000);
  if (! rtc.begin()) {
    Serial.write("Couldn't find RTC");
    while (1);
  }

  if (rtc.lostPower()) {
    Serial.write("RTC lost power, lets set the time!");
    // following line sets the RTC to the date & time this sketch was compiled
    rtc.adjust(DateTime(F(__DATE__), F(__TIME__)));

  }
  status = BMP.begin(0x76);
  if (!status) {
    while (1);
  }
  delayTime = 20000;

}


void loop() {

  temperature = (int)BMP.readTemperature();
 // humidity = (int)BMP.readHumidity();
  pressure = (int)(BMP.readPressure() / 100.0F);

  // Let's see the reading that will determine the forecast

 // Serial.print("Measured altitude ");
 // Serial.write((int)BMP.readAltitude(SEALEVELPRESSURE_HPA));

  int seapressure = station2sealevel(pressure, altitude, temperature); //is defined later in the code

 
 
  DateTime now = rtc.now();
  int t_hour2 = now.hour();
  int t_minute2 = now.minute();
 // int t_second2 = now.second();

  if (t_hour2 != t_hour or t_minute2 != t_minute) {
    delta_time++;
    if (delta_time > 10) {    // every minute we increment delta_time, then every 10 minutes
      delta_time = 0;         // we store the value in the array 

      if (counter == 10)  // if we read 10 values and filled up the array, we shift the array content
      {
        for (int i = 0; i < 9; i++) {   // we shift the array one position to the left
          pressureArray[i] = pressureArray[i + 1];
        }
        pressureArray[counter - 1] = seapressure;
      }
      else {        // this code fills up the pressure array value by value until is filled up
        pressureArray[counter] = seapressure;
        counter++;
      }
    }

    Z = calc_zambretti((pressureArray[9] + pressureArray[8] + pressureArray[7]) / 3, (pressureArray[0] + pressureArray[1] + pressureArray[2]) / 3, now.month());
//is defined later
    if (pressureArray[9] > 0 and pressureArray[0] > 0) {
      if (pressureArray[9] + pressureArray[8] + pressureArray[7] - pressureArray[0] - pressureArray[1] - pressureArray[2] >= 3) {
        //RAISING
        Serial.print("[>] ");
     if (Z<2){
          Serial.write("Settled Fine");
        }
        else if (Z>1 and Z<=2){
          Serial.write("Fine Weather");
           }
        else if (Z>2 and Z<=3){
          Serial.write("Becoming Fine");
        }
        else if (Z>3 and Z<=4){
          Serial.write("Fine  Becoming Less Settled");
          }
        else if (Z>4 and Z<=5){
          Serial.write("Fine  Possibly Showers");
           }
        else if (Z>5 and Z<=6){
          Serial.write("Fairly Fine  Improving");
            }
        else if (Z>6 and Z<=7){
          Serial.write("Fairly Fine Pos.Showers, early  ");
           }
        else if (Z>7 and Z<=8){
          Serial.write("Fairly Fine     Showery Later   ");
           }
        else if (Z>8 and Z<=9){
          Serial.write("Showery Early   Improving       ");
           }
        else if (Z>9 and Z<=10){
          Serial.write("Changeable      Mending         ");
            }
        else if (Z>10 and Z<=11){
          Serial.write("Fairly Fine     Showers likely  ");
          }
        else if (Z>11 and Z<=12){
          Serial.write("Rather UnsettledClearing Later  ");
          }
        else if (Z>12 and Z<=13){
          Serial.write("Unsettled Prob. Improving       ");
          }
        else if (Z>13 and Z<=14){
          Serial.write("Showery Bright  Intervals       ");
          }
        else if (Z>14 and Z<=15){
          Serial.write("Showery BecomingMore Unsettled  ");
           }
        else if (Z>15 and Z<=16){
          Serial.write("Changeable      Some Rain       ");
          }
        else if (Z>16 and Z<=17){
          Serial.write("Unsettled Short Fine Intervals  ");
        }
        else if (Z>17 and Z<=18){
          Serial.write("Unsettled       Rain later      ");
          }
        else if (Z>18 and Z<=19){
          Serial.write("Unsettled       Rain at time    ");
          }
        else if (Z>19 and Z<=20){
          Serial.write("Very Unsettled  Finer at time   ");
          }
        else if (Z>20 and Z<=21){
          Serial.write("Rain at times   Worse later");
          }
        else if (Z>21 and Z<=22){
          Serial.write("Rain at times   Bec. Very Uns.  ");
          }
        else if (Z>22 and Z<=23){
          Serial.write("Rain at Frequent Intervals");
          }
        else if (Z>23 and Z<=24){
          Serial.write("Very Unsettled  Rain");
          }
        else if (Z>24 and Z<=25){
          Serial.write("Stormy possibly Improving");
          }
        else if (Z>25 and Z<=26){
          Serial.write("Stormy  Much Rain");
         
          }
      }
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
